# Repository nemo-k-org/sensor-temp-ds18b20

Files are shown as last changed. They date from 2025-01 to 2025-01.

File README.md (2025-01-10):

# Nemo-K temperature sensor for DS18B20

## Overview

This is Nemo-K board for ESP-01 and well-known [DS18B20](https://www.analog.com/en/products/ds18b20.html) gauge.

Because of its measuring range (-55°C to +125°C, -67°F to +257°F) DS18B20 is ideal for all marine temperature
measurements e.g. salons, engine coolant, engine room. However, using this gauge for measuring except exhaust
pipe temperatures is out of its range.

The board is designed to be used with ESP-01 microcontroller running Nemo-K firmware.

## Content

The repository contains schematics and PCB in KiCad 8.0 format. The footprint properties contains LCSC part numbers
used by [JLCPBC.com](https://jlcpcb.com). If present, the `sensor-temp-ds18b20/production/` contains all necessary
files to order boards from JLCPCB. The production files can be easily re-created using
[KiCad Fabrication Toolkit](https://github.com/bennymeg/Fabrication-Toolkit).

The Nemo-K project is not affiliated or sponsored by JLCPCB. The project does not endorse JLCPCB.

## Changelog

* *v2* First working version. The labels "Sens Data" and "Sens 3.3V" of the temperature sensor screw terminal
  are the wrong way around. A reverse polarity protection diode should be added.

## Copyright and License

The license and copyright can be found in the file `LICENSE`.

The license and copyright cover only the schematic diagram and the PCB design. It does not cover footprints and other
embedded elements or technical documentation which may or may not be covered by their own licenses.

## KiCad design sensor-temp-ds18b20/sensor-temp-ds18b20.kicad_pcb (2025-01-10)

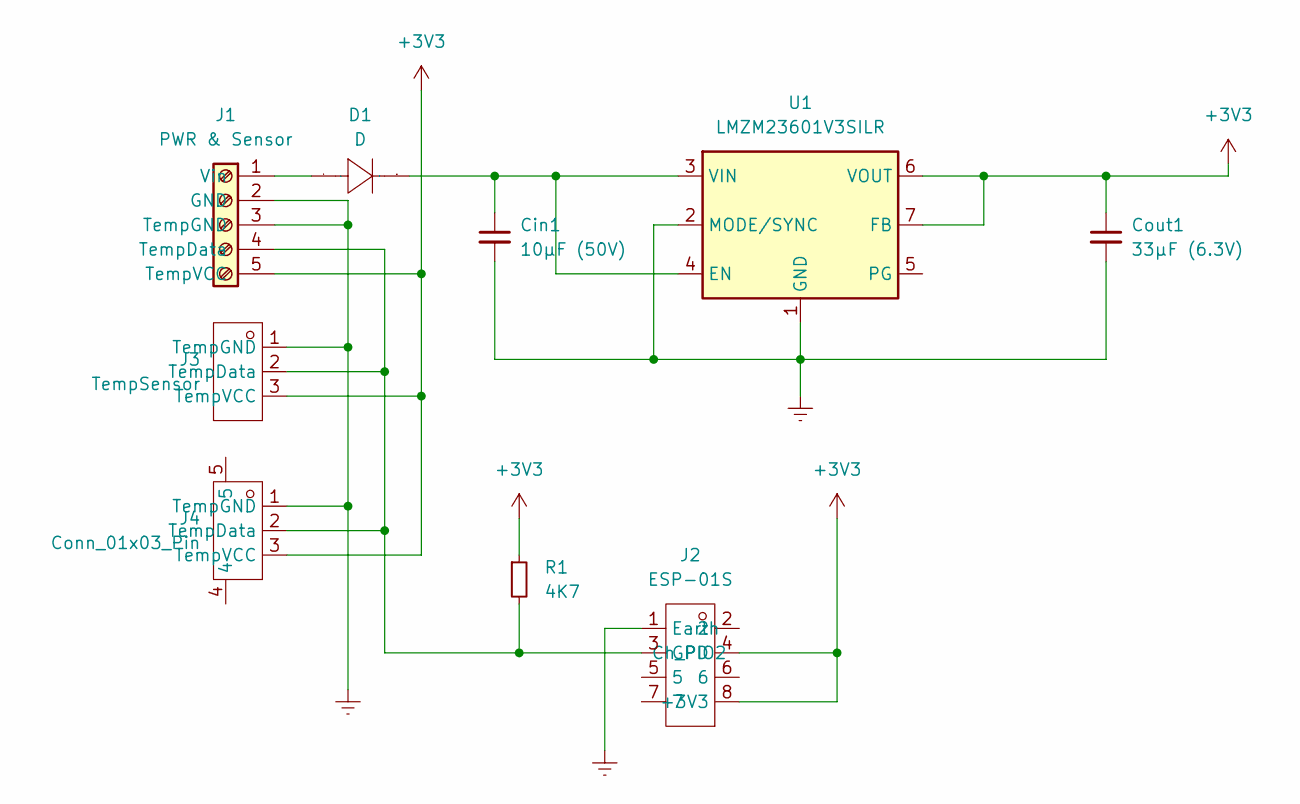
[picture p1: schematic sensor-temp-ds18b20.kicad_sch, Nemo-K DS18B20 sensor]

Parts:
Cin1: 10μF (50V); C_1210_3225Metric; LCSC C2918502
Cout1: 33μF (6.3V); C_1210_3225Metric; Mfg Part C3225X5R1A336MT0A0E; LCSC C531418
D1: D; SOD-323_L1.7-W1.3-LS2.5-RD; Manufacturer Part S7116-300A; LCSC Part Name S7116-300A
J1: PWR & Sensor; TerminalBlock_MetzConnect_Type086_RT03405HBLC_1x05_P3.81mm_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; MPN OSTOQ053251; LCSC C5349553
J2: ESP-01S; HDR-SMD_8P-P2.54-V-F-R2-C4-S7.1; Mfg Part PM254-2-04-S-8.5; LCSC C3975149
J3: TempSensor; HDR-TH_3P-P2.54_DZ254S-11-03-48; Manufacturer Part DZ254S-11-03-48; LCSC Part Name 间距:2.54mm 1x3P 立贴 方针
J4: Conn_01x03_Pin; CONN-SMD_3P-P2.50_SHOUHAN_2.54-3PWTDK; Manufacturer Part 2.54-3PWTDK; LCSC Part Name 1x3P 间距:2.5mm 卧贴
R1: 4K7; R_1206_3216Metric; LCSC C17936
U1: LMZM23601V3SILR; Texas_SIL0010A_MicroSiP-10-1EP_3.8x3mm_P0.6mm_EP0.7x2.9mm_T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; MPN LMZM23601SILR; LCSC C2864948

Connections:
+3V3: Cout1.1, J1.5 (TempVCC), J2.4 (Ch_PD), J2.8 (+3V3), J3.3 (TempVCC), J4.3 (TempVCC), R1.1, U1.6 (VOUT), U1.7 (FB)
Earth: Cin1.2, Cout1.2, J1.2 (GND), J1.3 (TempGND), J2.1 (Earth), J3.1 (TempGND), J4.1 (TempGND), U1.1 (GND), U1.2 (MODE/SYNC), U1.11 (GND)
unnamed: D1.2 (A), J1.1 (Vin)
unnamed: Cin1.1, D1.1 (K), U1.3 (VIN), U1.4 (EN)
unnamed: J1.4 (TempData), J2.3 (GPIO2), J3.2 (TempData), J4.2 (TempData), R1.2

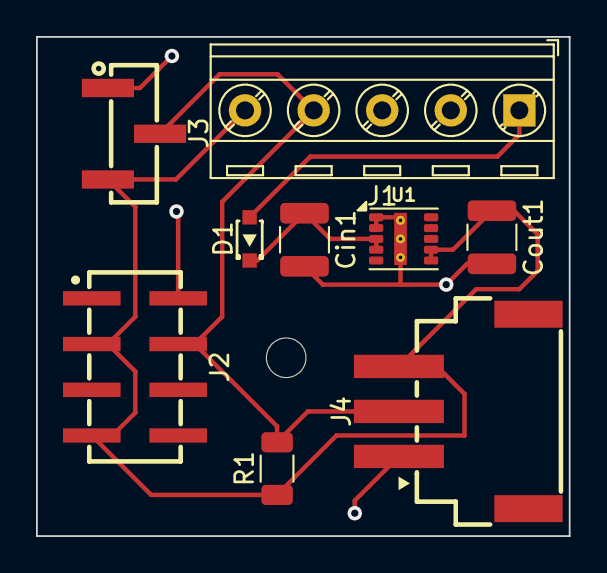
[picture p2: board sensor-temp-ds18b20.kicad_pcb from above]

Board: 2 copper layers, 29.6 x 27.7 mm, 9 parts (0 on the bottom side), 5 nets.

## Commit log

2025-01-10 v2, the first working version
    [sensor-temp-ds18b20.kicad_pcb, sensor-temp-ds18b20.kicad_sch]
2025-01-10 Switch labels "Sens Data" and "Sens 3.3V" in the screw terminal J1
    [sensor-temp-ds18b20.kicad_pcb]
2025-01-10 Added reverse polarity protection and fixed the footprint paths
    [sensor-temp-ds18b20.kicad_pcb, sensor-temp-ds18b20.kicad_sch]
